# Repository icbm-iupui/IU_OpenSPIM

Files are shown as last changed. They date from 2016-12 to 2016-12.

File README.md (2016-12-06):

12/6/16. Additions by Indiana University, Indiana Center for Biological Microscopy
Seth Winfree completed 2015.

This repo contains the IU-OpenSPIM additions made to support NEOS AOTF control 
and filterwheel control on the emission from within the plugin.  These are supported
in the multiview acquisition tab and via a new DAC slider control for setting AOTF
transmission and filterwheel position.

This repo was orginally forked in 2015 with the intention of pulling it back to
the master but in the time I forked it and made my changes, significant changes
were made to the master making it difficult to merge.  Thus, for now, this is record
of the changes that could be implemented in the current OpenSPIM plugin to 
support an AOTF and FW from within the plugin.  

# Original README

The [OpenSPIM](http://openspim.org/) project is a collaboration between multiple
labs to establish an accessible, easily adjustable light sheet microscope
system.

The *SPIMAcquisition* plugin for [Micro Manager](https://micro-manager.org) is
the primary means to acquire image stacks with the OpenSPIM setups.

# How to build

To build this plugin, two extra steps are required before letting Maven (or
any Integrated Development Environment with a Maven integration) build the
project: The Micro-Manager artifacts need to be installed locally because they
are not available via any public Maven repository yet.

Assuming that you already have a nightly build (e.g. by following the
[Micro-Manager-dev update site](http://sites.imagej.net/Micro-Manager-dev/)),
install the artifacts into your local Maven repository by executing the
following two commands inside the `ImageJ.app/` directory containing
Micro-Manager:

```bash
cd plugins/Micro-Manager
mvn install:install-file -DgroupId=org.micromanager -Dversion=1.4.21-SNAPSHOT \
	-Dpackaging=jar -DartifactId=MMJ_ -Dfile=MMJ_.jar
mvn install:install-file -DgroupId=org.micromanager -Dversion=1.4.21-SNAPSHOT \
	-Dpackaging=jar -DartifactId=MMCoreJ -Dfile=MMCoreJ.jar
```

After that, a simple `mvn -Dscijava.enforce.skip` will build the
`SPIMAcquisition` plugin which can then be installed by copying
`target/SPIMAcquisition-<version>.jar` into `Fiji.app/mmplugins/`.

# Installing into a Micro-Manager directory instead of Fiji

The SPIMAcquisition plugin depends on a couple of components that are shipped
with Fiji but not with Micro-Manager. Therefore, you will have to work a little
harder if you want to install the plugin into a vanilla Micro-Manager as
downloaded from [the Micro-Manager website](https://micro-manager.org):

1. Run `mvn dependency:copy-dependencies` in the SPIMAcquisition directory
2. From `target/dependency/` in that subdirectory, copy the `imglib2-*.jar` files to your Micro-Manager's `mmplugins/` subdirectory.
3. Copy `target/SPIMAcquisition-1.0.0-SNAPSHOT.jar` to the `mmplugins/` subdirectory, too.
4. Restart Micro-Manager.

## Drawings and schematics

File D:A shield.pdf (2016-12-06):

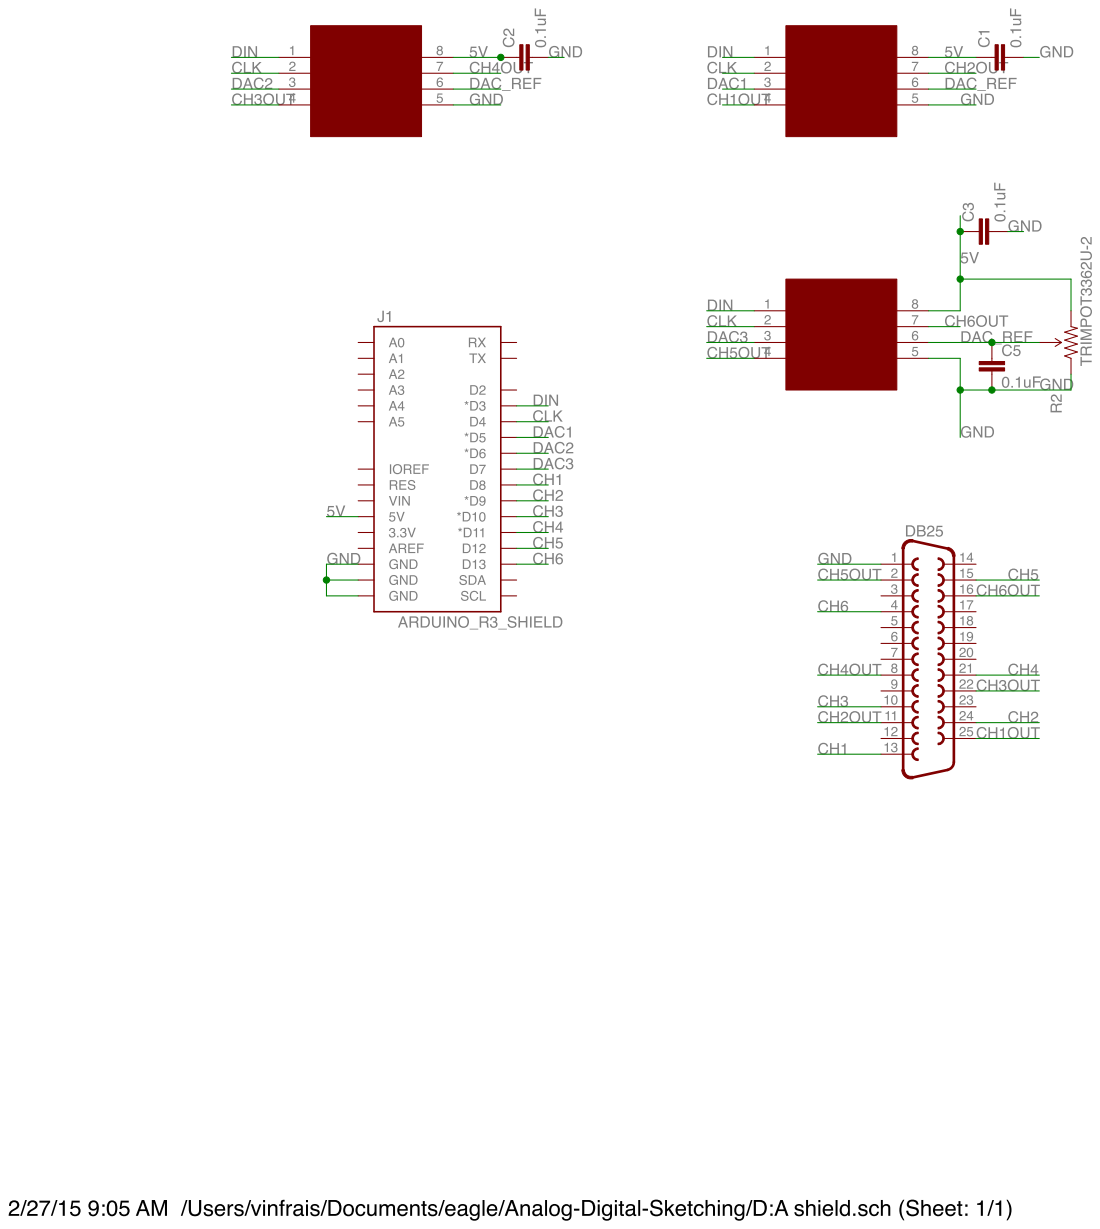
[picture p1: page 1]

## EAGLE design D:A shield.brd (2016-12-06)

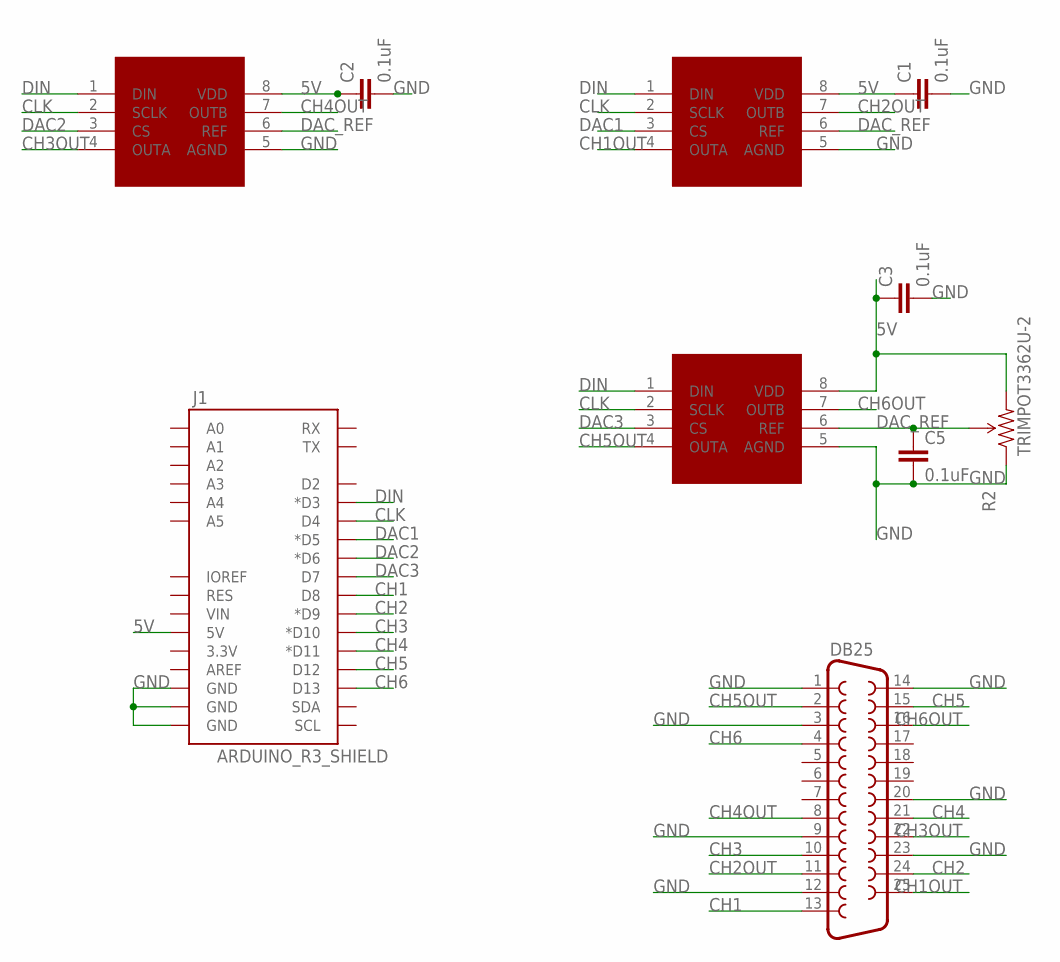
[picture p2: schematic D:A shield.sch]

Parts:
C1, C2, C3, C5: 0.1uF; 1206
DAC1, DAC2, DAC3: TLV5618; DIL08
DB25: F25HP
J1: ARDUINO_R3_SHIELD; UNO_R3_SHIELD
R2: TRIMPOT3362U-2; 3362U-2

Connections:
5V: C1.1, C2.1, C3.1, DAC1.8 (VDD), DAC2.8 (VDD), DAC3.8 (VDD), J1.5V, R2.3 (CW)
CH1: DB25.13, J1.D8
CH1OUT: DAC1.4 (OUTA), DB25.25
CH2: DB25.24, J1.D9 (*D9)
CH2OUT: DAC1.7 (OUTB), DB25.11
CH3: DB25.10, J1.D10 (*D10)
CH3OUT: DAC3.4 (OUTA), DB25.22
CH4: DB25.21, J1.D11 (*D11)
CH4OUT: DAC3.7 (OUTB), DB25.8
CH5: DB25.15, J1.D12
CH5OUT: DAC2.4 (OUTA), DB25.2
CH6: DB25.4, J1.D13
CH6OUT: DAC2.7 (OUTB), DB25.16
CLK: DAC1.2 (SCLK), DAC2.2 (SCLK), DAC3.2 (SCLK), J1.D4
DAC1: DAC1.3 (CS), J1.D5 (*D5)
DAC2: DAC3.3 (CS), J1.D6 (*D6)
DAC3: DAC2.3 (CS), J1.D7
DAC_REF: C5.1, DAC1.6 (REF), DAC2.6 (REF), DAC3.6 (REF), R2.2 (WIPER)
DIN: DAC1.1 (DIN), DAC2.1 (DIN), DAC3.1 (DIN), J1.D3 (*D3)
GND: C1.2, C2.2, C3.2, C5.2, DAC1.5 (AGND), DAC2.5 (AGND), DAC3.5 (AGND), DB25.1, DB25.3, DB25.9, DB25.12, DB25.14, DB25.20, DB25.23, J1.GND@0 (GND), J1.GND@1 (GND), J1.GND@2 (GND), R2.1 (CCW)

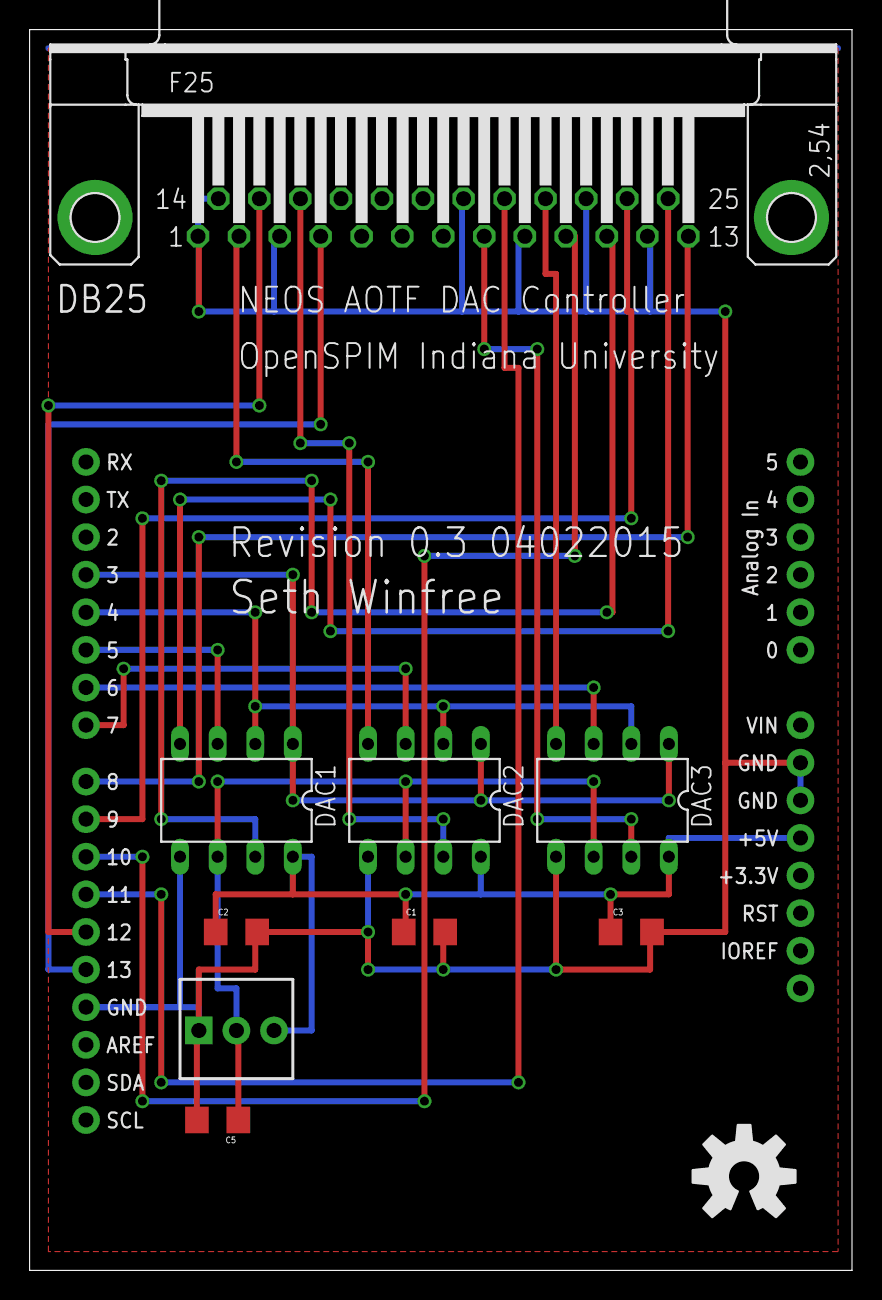
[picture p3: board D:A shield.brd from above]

Board: 2 copper layers, 55.5 x 83.8 mm, 11 parts (0 on the bottom side), 20 nets.

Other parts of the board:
U$1: OSHW-LOGO-L

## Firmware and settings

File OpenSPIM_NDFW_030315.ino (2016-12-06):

/* 
This is a test sketch for the Adafruit assembled Motor Shield for Arduino v2
It won't work with v1.x motor shields! Only for the v2's with built in PWM
control

For use with the Adafruit Motor Shield v2 
---->	http://www.adafruit.com/products/1438
*/


#include <Wire.h>
#include <Adafruit_MotorShield.h>
#include <AFMotor.h>
#include "utility/Adafruit_PWMServoDriver.h"
#include <Adafruit_MCP23017.h>
#include <Adafruit_RGBLCDShield.h>
#include "Tlc5940.h"

//lighting via TLC5940
TLC_CHANNEL_TYPE channel;





// Create the motor shield object with the default I2C address
Adafruit_MotorShield AFMS = Adafruit_MotorShield(); 
Adafruit_DCMotor *pumpIn = AFMS.getMotor(4);
Adafruit_DCMotor *pumpOut = AFMS.getMotor(3);
Adafruit_RGBLCDShield lcd = Adafruit_RGBLCDShield();

#define RED 0x1
#define YELLOW 0x3
#define GREEN 0x2
#define TEAL 0x6
#define BLUE 0x4
#define VIOLET 0x5
#define WHITE 0x7
#define MOVEMENTDELAY 100
#define LIGHTON 2000
#define LIGHTOFF 0
#define NDFW 0
#define PERF 1


int menu = NDFW;

// Connect a stepper motor with 200 steps per revolution (1.8 degree)
// to motor port #2 (M3 and M4)
Adafruit_StepperMotor *myMotor = AFMS.getStepper(200, 1);
int homeloop = 0;
int currentPosition = 0;
boolean perfusionState = false;
boolean perfusionForward = true;
boolean empty = false;
volatile double sensorValue;
String positionLabels[] = {"MIR ", "ND5  ", "ND4  ", "ND3  ", "ND2 ", "OPEN"};
String perfusionLabels[] = {"OFF", "ON FR", "EMPTY ", "ON RV"};
 
 
 
 

void setup() {
  
  Serial.begin(9600);           // set up Serial library at 9600 bps
  Serial.println("Stepper test!");
  Serial.println("Double coil");
  lcd.begin(16, 2);
  lcd.setCursor(0, 0);
  lcd.print("IU OpenSPIM NDFW");
  
   
  lcd.setCursor(0, 1);
  lcd.print("Starting light...");
  
  Tlc.init();
  lightOn();

  
  AFMS.begin();  
    coarseHomeWheel();
    coarseHomeWheel();
   
    setMenu();
    
    delay(1000); 
     
     
  //run loop
}

void loop() {
 while(homeloop <= 12){
 readButtons();
 delay(MOVEMENTDELAY);
 }
 goToPosition(0);
 coarseHomeWheel();
}
  

 void coarseHomeWheel(){
   int lastPosition = currentPosition;
  lcd.setBacklight(RED);
  lcd.setCursor(0, 1);
  lcd.print("Homing wheel...     ");
  sensorValue = analogRead(A0);
  myMotor->setSpeed(50);  // 10 rpm   
    while(sensorValue<=50){
      lcd.print("Homing wheel...     ");
      sensorValue = analogRead(A0);
      delay(100);
      sensorValue = analogRead(A0);
      myMotor->step(1, FORWARD, DOUBLE); 
      sensorValue = analogRead(A0);
      currentPosition = 0;
      lcd.setCursor(0,1);
  }
  lcd.setBacklight(WHITE);
  lcd.setCursor(0,1);
  lcd.print("At Filter: " + positionLabels[currentPosition] + "     ");
  goToPosition(lastPosition);
  homeloop = 0;
 }
 
 void readButtons(){
   uint8_t buttons = lcd.readButtons();
   int selection = 0;
   

  if (buttons) {
    lcd.clear();
    lcd.setCursor(0,0);
    if(menu == NDFW){
      if (buttons & BUTTON_UP) {
      lightOn();
      setMenu();
    }
    if (buttons & BUTTON_DOWN) {
      lightOff();
      setMenu();
    }
    if (buttons & BUTTON_LEFT) {
      setMenu();
      lcd.setCursor(0,1);
      moveBackward(true);
      lcd.setBacklight(WHITE);
    } 
    if (buttons & BUTTON_RIGHT) {
      setMenu();
      lcd.setCursor(0,1);
      moveForward(true);
      lcd.setBacklight(WHITE);
    }
    }
    if(menu == PERF){
    boolean b = !perfusionState;
    if (buttons & BUTTON_LEFT){
      stopPumps();
      setMenu();
    }
    if (buttons & BUTTON_RIGHT) {
      startPumps();
      setMenu();
    } 
    if (buttons & BUTTON_DOWN) {
      emptyChamber();
      empty = true;
      setMenu();
    }
    if (buttons & BUTTON_UP) {
      startPumpsReverse();
      setMenu();
    }
    }
    }
    if (buttons & BUTTON_SELECT) {
      if(menu == NDFW){menu = PERF;}
      else{menu = NDFW;}
      setMenu();
    }
 }
 

//Setup LCD menu
 void setMenu(){
   if(menu == NDFW){
   lcd.clear();
   lcd.setCursor(0, 0);
   lcd.setBacklight(WHITE);
   lcd.print("IU OpenSPIM NDFW");
   lcd.setCursor(0, 1);
    lcd.print("At Filter: " + positionLabels[currentPosition] + "     ");
   }
   else{
   lcd.clear();
   lcd.setCursor(0, 0);
   lcd.setBacklight(WHITE);
   lcd.print("IU OpenSPIM PERF");
   lcd.setCursor(0, 1);
   if(perfusionState){
     if(perfusionForward){
   lcd.print("Perfusion: " + perfusionLabels[1] + "     ");
     }
     else{
       lcd.print("Perfusion: " + perfusionLabels[3] + "     ");
     }
   }else if(empty){
     lcd.print("Perfusion: " + perfusionLabels[2] + "     ");
    
   }else{
     lcd.print("Perfusion: " + perfusionLabels[0] + "     ");
   }
   }
 
 }
 
 //move forward
 void moveForward(boolean count){
 myMotor->setSpeed(100); 
 myMotor->step(33, FORWARD, DOUBLE); 
 
 if(currentPosition == 5){
   currentPosition = 0;
 }
 else {
   currentPosition++;
 }
 lcd.print("At Filter: " + positionLabels[currentPosition] + "     ");
 if(count == true){homeloop++;}
 }
 
 //move backward
 void moveBackward(boolean count){
  myMotor->setSpeed(100); 
 myMotor->step(33, BACKWARD, DOUBLE); 
  
  
 if(currentPosition == 0){
   currentPosition = 5;
 }
 else {
   currentPosition--;
 }
 lcd.print("At Filter: " + positionLabels[currentPosition] + "     ");
 if(count == true){homeloop++;}
 }
 
 //goto select position
 boolean goToPosition(int position){     
       while(currentPosition != position){
         lcd.setBacklight(RED);
         lcd.setCursor(0,1);
         moveForward(false);
       }  
 return true;      
 }
 
 //turn BL off
 
 void lightOff(){
   for(int i = 0; i <= 20; i++){   
     Tlc.set(i, LIGHTOFF); 
     delay(5); 
     Tlc.update();    
  }
 }
 
 //turn BL on

 void lightOn(){ 
   for(int i = 0; i <= 20; i++){   
     Tlc.set(i, LIGHTON); 
     delay(5); 
     Tlc.update();    
  }
 }
 
 //start perfusion pumps
 
 void startPumps(){
 
 pumpIn->setSpeed(100); 
 pumpOut->setSpeed(115);
 pumpIn->run(FORWARD);
 pumpOut->run(BACKWARD);
 perfusionState = true;
 perfusionForward = true;
 empty = false;
 }
 
  //stop perfusion pumps
 
 void stopPumps(){
 
pumpIn->setSpeed(0);
 pumpOut->setSpeed(0);
 pumpIn->run(RELEASE);
 pumpOut->run(RELEASE);
 perfusionState = false;
 empty = false;
 }
 
  void startPumpsReverse(){
 
 pumpIn->setSpeed(255); 
 pumpOut->setSpeed(200);
 pumpIn->run(BACKWARD);
 pumpOut->run(FORWARD);
 perfusionState = true;
 perfusionForward = false;
 empty = false;
 }
 
 void emptyChamber(){
  pumpIn->setSpeed(0); 
  pumpOut->setSpeed(0); 
  pumpOut->run(RELEASE); 
  pumpIn->run(BACKWARD);
  pumpIn->setSpeed(65000);  
  perfusionState = false;
  empty = true;
 }
 

 

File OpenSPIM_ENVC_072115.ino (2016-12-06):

/* Open-Spim Temperature and CO2 Perfusion Control
 *  
 *  Seth Winfree and Nathaniel Smith
 *  
 *  This code uses the following libraries and reference codes:
 *    The "Hello World" code from Adafruit's RGB LCD Shield Library
 *    "DC MotorTest" code from Adafruit's Motor Shield V2 Library
 *    "singleended" code from Adafruit's ADS1015 Library
 *    "PID_Basic" and "PID_AdaptiveTunings" code from the Arduino PID Library - Version 1.1.1 by Brett Beauregard
 *    "Using a Thermistor" code provided by Adafruit at https://learn.adafruit.com/thermistor/using-a-thermistor
 *    PID parameters were tuned according to the Classic Ziegler-Nichols Rule, which can be found at http://www.mstarlabs.com/control/znrule.html
 * 
 */

// Included Libraries
#include <Wire.h>
#include <Adafruit_MCP23017.h>
#include <Adafruit_RGBLCDShield.h>
#include <Adafruit_MotorShield.h>
#include <Adafruit_ADS1015.h>
#include <math.h>
#include <PID_v1.h>

// Initial Settings and Definitions
Adafruit_RGBLCDShield lcd = Adafruit_RGBLCDShield();
Adafruit_ADS1015 ads1 = Adafruit_ADS1015(0x48);    
Adafruit_ADS1015 ads2 = Adafruit_ADS1015(0x49); 
Adafruit_MotorShield AFMS = Adafruit_MotorShield(0x60); 
Adafruit_DCMotor *pump = AFMS.getMotor(1);
int time = 0;
double steinhart0, steinhart1;
double adc0, adc1;

// This definition will be used to define the LCD backlight color
#define GREEN 0x2
#define WHITE 0x7

//Define the PID variables we'll be using
double Setpoint, Input, Output;
double minOutput = 0;
double maxOutput = 255;

//Define the PID tuning parameters
double aggKp=120, aggKi=60, aggKd=15;

//Specify the links and tuning parameters
PID myPID(&Input, &Output, &Setpoint, aggKp, aggKi, aggKd, DIRECT);

void setup() {

  Serial.begin(9600);
  ads1.begin();
  //ads2.begin();
  lcd.begin(16, 2);
  lcd.setBacklight(WHITE);
  Wire.begin();
  AFMS.begin();
    
  pump->run(FORWARD);
  //Serial.println("CLEARDATA");
  //Serial.println("LABEL, Timepoint, Time, T-Sample, T-Sample 2, Average Temperature, Error, Motor Setting (75-255)");

  //initialize the PID variables
  Input = 25;
  Setpoint = 37.1;

  // Use LCD to allow user to select a setpoint temperature
  uint8_t buttons = lcd.readButtons();
  lcd.setCursor(0,0);
  lcd.print(String("IU OpenSPIM ENVC"));
  lcd.setCursor(0,1);
  lcd.print(String("Set T(C):"));

  while (buttons != BUTTON_SELECT) {
    buttons = lcd.readButtons();
    lcd.setCursor(10,1);
    lcd.print(Setpoint);
    if (buttons & BUTTON_UP) {
      lcd.setCursor(10,1);
      Setpoint += .1;
      lcd.print(Setpoint);
    }
    if (buttons & BUTTON_DOWN) {
      lcd.setCursor(10,1);
      Setpoint -= .1;
      lcd.print(Setpoint);
    }
    delay(100);
  }
  
  //Setpoint += .05;

  //turn the PID on
  myPID.SetMode(AUTOMATIC);
  myPID.SetOutputLimits(minOutput,maxOutput); 
}

void loop() {

  // Read temperature sensors and calculate resistance
  adc0 = ads1.readADC_SingleEnded(0);
  adc1 = ads1.readADC_SingleEnded(1);
  double resistance0=2000/(1/((.003)*adc0)-.2);
  double resistance1=2000/(1/((.003)*adc1)-.2);
  
  delay(100);

  // Use resistance to calculate a temperature using the Steinhart-Hart B parameter equation method
  steinhart0 = resistance0/10000;     // (R/Ro)
  steinhart0 = log(steinhart0);                  // ln(R/Ro)
  steinhart0 /= 3950;                   // 1/B * ln(R/Ro)
  steinhart0 += 1.0 /( 25 + 273.15); // + (1/To)
  steinhart0 = 1.0 / steinhart0;                 // Invert
  steinhart0 -= 273.15;                         // convert to C
  steinhart1 = resistance1/10000;     // (R/Ro)
  steinhart1 = log(steinhart1);                  // ln(R/Ro)
  steinhart1 /= 3950;                   // 1/B * ln(R/Ro)
  steinhart1 += 1.0 /( 25 + 273.15); // + (1/To)
  steinhart1 = 1.0 / steinhart1;                 // Invert
  steinhart1 -= 273.15;                         // convert to C

  delay(100);

  // Display the temperature of the sample and reservoir on the LCD
  lcd.clear();
  lcd.setCursor(0,0);
  lcd.print(String("IU OpenSPIM ENVC"));
  lcd.setCursor(0,1);
  lcd.print(String("Sample: ")+steinhart0);
  lcd.setCursor(13 ,1);  
  lcd.print(String("(C)"));
  //lcd.print(String("Air: ")+steinhart1);

  delay(1000);
  
    lcd.clear();
  lcd.setCursor(0,0);
  lcd.print(String("IU OpenSPIM ENVC"));
  lcd.setCursor(0,1);
  lcd.print(String("Resrv.: ")+steinhart1);
  lcd.setCursor(13 ,1);  
  lcd.print(String("(C)"));

  // Print the temperature of the sample and reservoir to serial
  time += 5;
  //Serial.print(time);
  //Serial.print(String("     ")+ steinhart0+String("      "));
  //Serial.print(steinhart1+String("   "));

  delay(100);
  
  Input = steinhart0;
  double Inputswitchpoint = .95*Setpoint;
    
  if (Input < Inputswitchpoint) {
    Output = 255;
    }
  
  // Calculate a PID output for the motor, given the temperature of the sample
  /*else*/ if (isnan(steinhart0) == 0) {  
  myPID.SetTunings(aggKp, aggKi, aggKd);

  myPID.Compute();

  // The peristaltic pump doesn't function at low voltages, so this redefines the output to low setting (45) or off (0)
  if (Output < 1) {
    Output = 0;
  }
  else if (Output < 45) { 
    Output = 45;
  }
    
  pump->setSpeed(Output); 

  delay(100);

  //Serial.print(Output);
  //Serial.println();

  //Serial.print("DATA,"); Serial.print("TIME,"); Serial.print(time); Serial.print(","); Serial.print(steinhart0); Serial.print(","); Serial.print(steinhart1); Serial.print(","); Serial.print((steinhart1+steinhart0)/2); Serial.print(","); Serial.print((fabs(steinhart1-steinhart0))/2); Serial.print(","); Serial.println(Output);
  
  delay(2500);
  }
  else {
    //Serial.println();
    delay(4600);
  }
}

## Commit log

2016-12-06 Adding SNAPSHOT jar and firmwares
    SNAPSHOT jar supporting the arduino DAC and filterwheel within the plugin, dll for arduino in micromanager (replaces) and three arduino firmwares for the DAC, control of a neutral density filter wheel and a pump controller for media, perfusion and temperature control with software PID.
    [OpenSPIM_ENVC_072115.ino, OpenSPIM_NDFW_030315.ino, microManagerFirmware_ArduinoDAC_021215.ino]
2016-12-06 Eagle PCB design files
    These files include the corrected shield design with all the channel grounds connected correctly. Happy soldering!
    [D:A shield.brd, D:A shield.sch]

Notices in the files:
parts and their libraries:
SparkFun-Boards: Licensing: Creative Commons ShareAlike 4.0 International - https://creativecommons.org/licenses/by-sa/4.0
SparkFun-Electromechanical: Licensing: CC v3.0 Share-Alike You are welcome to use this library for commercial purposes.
